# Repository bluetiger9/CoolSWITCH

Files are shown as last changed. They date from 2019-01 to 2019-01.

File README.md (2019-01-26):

# CoolSWITCH

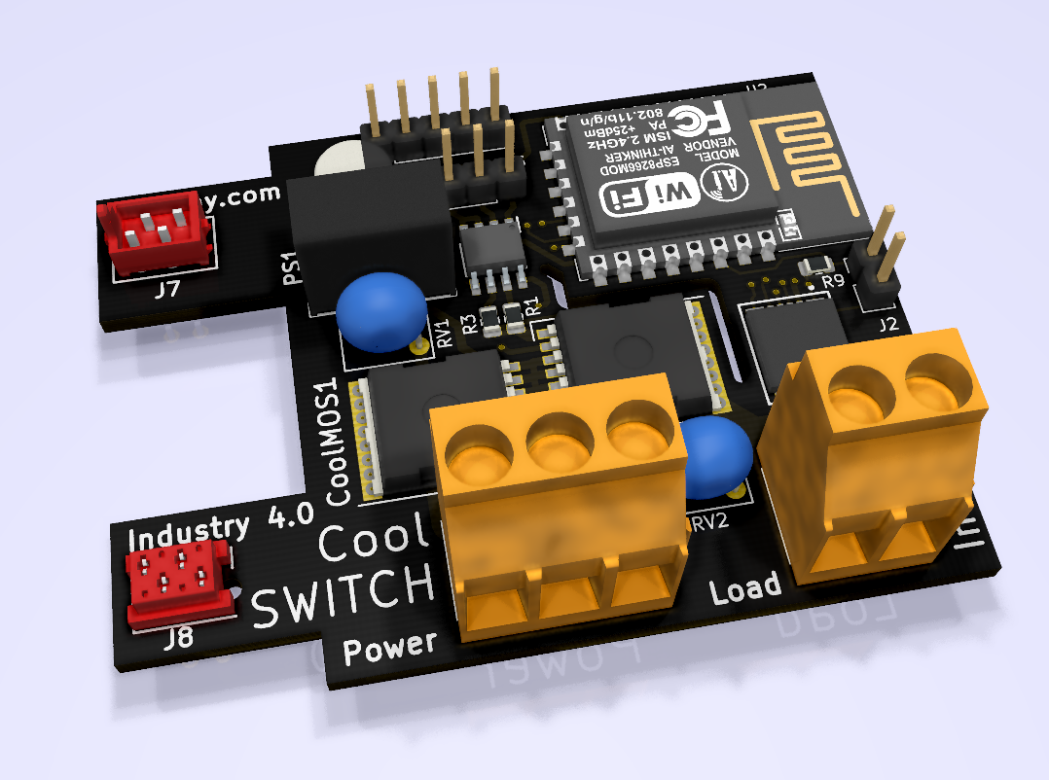
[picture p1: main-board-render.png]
CoolSWITCH


**Project structure**
- CoolSWITH-Kicad - Kicad project: schematics + PCB
- CoolSwitch - Arduino project
- Smashing-Dashboard - Smashing demo dashboard
- MQTT-Grafana - Grafana demo dashboard
- coolSwitchClient.py - secure HTTP client
 
**License**: 
- code: MIT
- kicad design: CC BY-NC-SA

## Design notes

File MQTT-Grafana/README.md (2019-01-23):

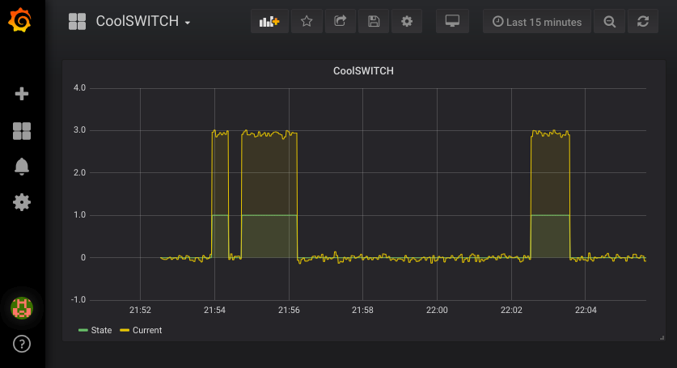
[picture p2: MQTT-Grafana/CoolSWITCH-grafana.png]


**docker-compose.yml**
 - run Mosquitto, InfluxDB and Grafana

**mqttToInflux.py**
 - listens for MQTT message sent by CoolSWITCH-s, and inserts the data into the InfluxDB

**CoolSWITCH-Grafana-Dashboard.json**
 - grafana Dashboard JSON Model

**Based on**:
https://gonzalo123.com/2018/06/04/playing-with-docker-mqtt-grafana-influxdb-python-and-arduino/

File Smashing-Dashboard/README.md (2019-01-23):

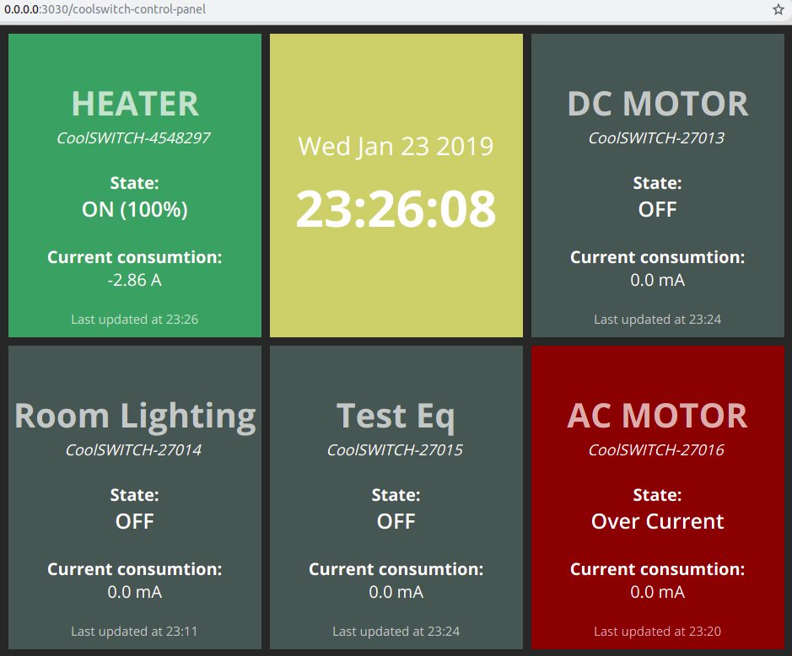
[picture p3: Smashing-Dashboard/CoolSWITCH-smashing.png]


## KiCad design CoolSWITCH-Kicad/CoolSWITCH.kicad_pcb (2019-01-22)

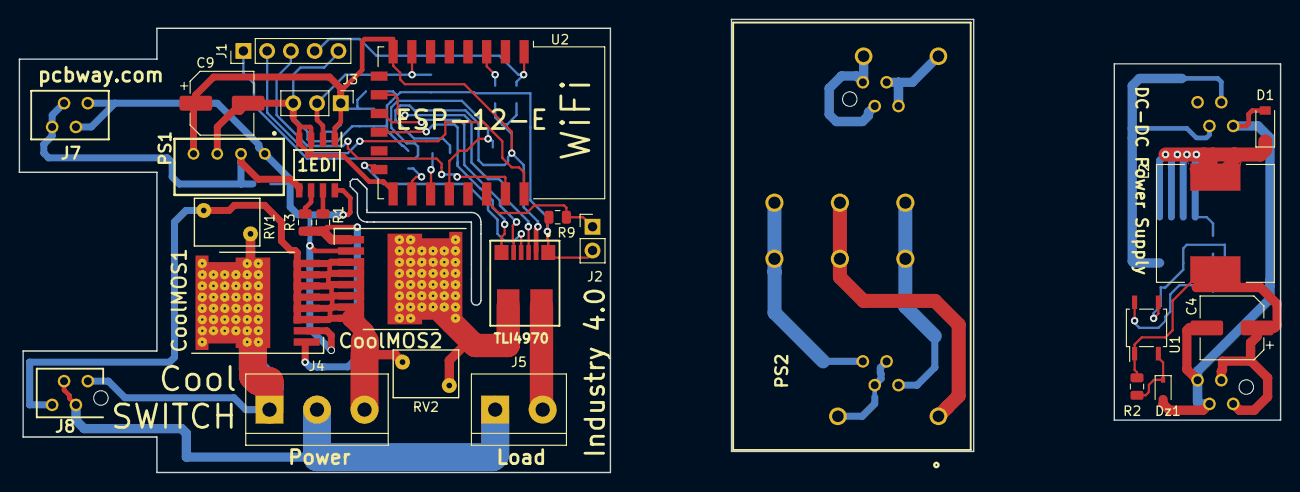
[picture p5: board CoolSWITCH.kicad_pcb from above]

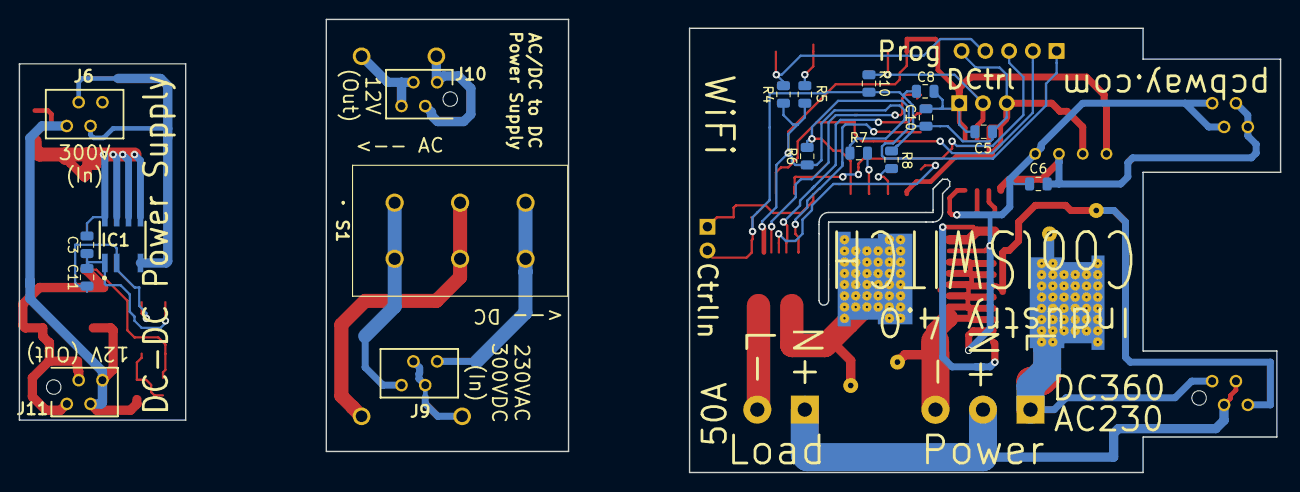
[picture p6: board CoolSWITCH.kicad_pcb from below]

Board: 2 copper layers, 134.9 x 48.5 mm, 44 parts (18 on the bottom side), 38 nets.

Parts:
1EDI: 1EDI20I12MFXUMA1; SOIC127P600X175-8N
C3: 0.1uF (25V); C_0805_2012Metric
C4: 220uF (16V); CP_Elec_6.3x7.7
C5, C8, C10: 100n; C_0805_2012Metric
C6: 1uF; C_0805_2012Metric
C9: 100u; CP_Elec_6.3x5.4
C11: 1nF (25V); C_0805_2012Metric
CoolMOS1, CoolMOS2: IPT60R028G7; Infineon_PG-HSOF-8-1_ThermalVias_fixed
D1: CD1408; D_SOD-123
Dz1: 11V; D_SOD-323
IC1: LNK3206D-TL; LNK3206D
J1: Prog; PinHeader_1x05_P2.54mm_Vertical
J2: CTRL_IN; PinHeader_1x02_P2.54mm_Vertical
J3: Direct_Ctrl; PinHeader_1x03_P2.54mm_Vertical
J4: POWER; TerminalBlock_bornier-3_P5.08mm
J5: LOAD; TerminalBlock_bornier-2_P5.08mm
J6, J9: PS_DC_IN; MicroMatch-215464-4
J7: PS_OUT; MicroMatch-215464-4
J8: PS_IN; MicroMatch-7-215079-4_1
J10: PS_DC_OUT; MicroMatch-7-215079-4_1
J11: PS_AC_OUT; MicroMatch-7-215079-4_1
L2: 1.2uH (400mA); L_12x12mm_H8mm
PS1: IE1203S; IE1224S-H
PS2: IRM-05-12; IRM-05-5
R1: 24 ohm (.5W); R_0805_2012Metric
R2: 1k (1%); R_0805_2012Metric
R3: 48 ohm (.5W); R_0805_2012Metric
R4, R5, R6, R7, R8, R9, R10: 10k; R_0805_2012Metric
RV1, RV2: 599V; RV_Disc_D7mm_W5.1mm_P5mm
S1: X22205CAAK
TLI4970: TLI4970D050T4XUMA1; PG-TISON-8-1
U1: PC817; SOP-4_3.8x4.1mm_P2.54mm
U2: ESP-12E; ESP-12E_2

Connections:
3.3V: 1EDI.1, C5.1, C8.1, C9.1, C10.2, J3.1, PS1.4, R4.1, R5.1, R6.1, R7.1, TLI4970.2, U2.8
12V: 1EDI.5, C6.1, C6.2, J7.1, J7.2, J7.3, J7.4, PS1.1, PS1.2
AC_IN_L: CoolMOS1.6, J4.1, J8.4, RV1.1
AC_IN_N: J4.2, J5.1, J8.2, J8.3
CRNT_CS: TLI4970.5, U2.11
CRNT_DOUT: TLI4970.3, U2.10
CRNT_OCD: TLI4970.6, U2.12
CRNT_SCLK: TLI4970.4, U2.14
CTRL_IN: J2.1, R9.1, U2.20
DC_IN_-: CoolMOS1.3, CoolMOS2.3, J4.3, J8.1, RV1.2, RV2.1
ESP_GPIO0: J1.1, R6.2, U2.18
ESP_RST: J1.4, R4.2, U2.1
ESP_RX: J1.3, U2.21
ESP_TX: J1.2, U2.22
GND: 1EDI.8, CoolMOS1.2, CoolMOS2.2
GND(logic): 1EDI.3, 1EDI.4, C5.2, C8.2, C9.2, C10.1, J1.5, J2.2, J3.3, PS1.3, R8.2, R9.2, R10.2, TLI4970.1, U2.15
Load: J5.2, TLI4970.8
Mosfet_En: 1EDI.2, J3.2, R10.1, U2.7
unnamed: C3.1, D1.1, IC1.5, IC1.6, IC1.7, IC1.8, L2.1
unnamed: C4.1, J11.3, J11.4, L2.2, R2.1, U1.1
unnamed: C4.2, D1.2, Dz1.2, J6.1, J11.1, J11.2
unnamed: C3.2, C11.1, IC1.1, U1.4
unnamed: C11.2, IC1.2, U1.3
unnamed: Dz1.1, R2.2, U1.2
unnamed: IC1.4, J6.2, J6.3
unnamed: 1EDI.6, R3.2
unnamed: 1EDI.7, R1.2
unnamed: CoolMOS2.6, RV2.2, TLI4970.7
unnamed: J9.1, S1.5, S1.6
unnamed: J9.2, J9.3, PS2.4
unnamed: J9.4, S1.1, S1.2
unnamed: J10.1, J10.2, PS2.2
unnamed: J10.3, J10.4, PS2.3
unnamed: PS2.1, S1.3, S1.4
unnamed: CoolMOS1.1, CoolMOS2.1, R1.1, R3.1
unnamed: R5.2, U2.3
unnamed: R7.2, U2.17
unnamed: R8.1, U2.16

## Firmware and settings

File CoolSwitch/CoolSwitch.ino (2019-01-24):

#include <ESP8266WiFi.h>
#include <ESP8266mDNS.h>
#include <WiFiUdp.h>
#include <ArduinoOTA.h>
#include <ESP8266WebServer.h>
#include <Tli4970.h>
#include <Arduino.h>
#include <FS.h>
//#include <SPIFFS.h>

#include "CoolSwitch.hpp"
#include "CoolSwitchHTTP.hpp"
#include "CoolSwitchMQTT.hpp"
#include "CoolSwitchConfig.hpp"

const uint8_t LED = 2;
const uint8_t MOSFET_EN = 13;

CoolSwitchConfig config;
CoolSwitch coolSwitch(MOSFET_EN);
CoolSwitchHTTP httpInterface(coolSwitch, config);
CoolSwitchMQTT mqttInterface(coolSwitch, config);

char deviceId[25];

void setupDeviceId() {
  uint32_t chipid = ESP.getChipId();
  snprintf(deviceId, 25, "CoolSWITCH-%d", chipid);
}

void setupConfig() {
  config.load();
}

void setupWifi() {
  if (config.wifiSSID != "") {
    Serial.print("Connecting to Wifi network: ");
    Serial.println(config.wifiSSID);
    char wifiSSID[32], wifiPassword[32];    
    config.wifiSSID.toCharArray(wifiSSID, 32);
    config.wifiPassword.toCharArray(wifiPassword, 32);
    WiFi.mode(WIFI_STA);
    WiFi.begin(wifiSSID, wifiPassword);
    while (WiFi.waitForConnectResult() != WL_CONNECTED) {
      //config.wifiSSID = "";
      //config.save();
      Serial.println("Connection Failed! Rebooting...");
      delay(5000);
      ESP.restart();
    }
    Serial.println("Wifi connected.");  
    Serial.print("  IP address: ");
    Serial.println(WiFi.localIP());
    
  } else {
    Serial.println("Setting up Wifi Soft AP:");
    WiFi.softAP(deviceId);
    Serial.print("  ssid: ");
    Serial.println(deviceId);
    Serial.print("  ip: 192.168.4.1");
  }  
}

void setupOTA() {
  // Port defaults to 8266
  // ArduinoOTA.setPort(8266);

  // Hostname defaults to esp8266-[ChipID]
  ArduinoOTA.setHostname(deviceId);

  // set OTA password
  if (config.httpSecret != "") {
    char otaPassword[128];
    config.httpSecret.toCharArray(otaPassword, 32);
    ArduinoOTA.setPassword(otaPassword);
  }

  ArduinoOTA.onStart([]() {
    coolSwitch.turnOff();
    Serial.println("Start");
  });
  
  ArduinoOTA.onEnd([]() {
    Serial.println("\nEnd");
  });
  
  ArduinoOTA.onProgress([](unsigned int progress, unsigned int total) {
    Serial.printf("Progress: %u%%\r", (progress / (total / 100)));
  });
  
  ArduinoOTA.onError([](ota_error_t error) {  
    Serial.printf("Error[%u]: ", error);
    if (error == OTA_AUTH_ERROR) Serial.println("Auth Failed");
    else if (error == OTA_BEGIN_ERROR) Serial.println("Begin Failed");
    else if (error == OTA_CONNECT_ERROR) Serial.println("Connect Failed");
    else if (error == OTA_RECEIVE_ERROR) Serial.println("Receive Failed");
    else if (error == OTA_END_ERROR) Serial.println("End Failed");
    ESP.restart();
  });
  
  ArduinoOTA.begin();
}

void setup() {
  Serial.begin(115200);
  Serial.println("Booting");
  pinMode(LED, OUTPUT);  

  setupDeviceId();
  setupConfig();
  setupWifi();
  setupOTA();

  coolSwitch.deviceName = deviceId;

  httpInterface.begin();
  mqttInterface.begin();

  delay(2000);

  coolSwitch.begin();
  
  Serial.println("CoolSWITCH Started.");
}


void loop() {
  ArduinoOTA.handle();
  httpInterface.handle();
  mqttInterface.handle();
  coolSwitch.handle();
  
}

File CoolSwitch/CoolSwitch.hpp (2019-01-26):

#ifndef COOL_SWITCH_H
#define COOL_SWITCH_H

#include "CoolSwitchCurrentSensor.hpp"

enum State { OFF, ON, SOFT_START, SOFT_STOP, OVER_CURRENT } ;

class PWMPin {
public:
  PWMPin(const uint8_t pin) 
    : pin(pin), speed(1024) {    
    pinMode(pin, OUTPUT);
    turnOff();
  };

  void setSpeed(const float speedPercent) {
    uint16_t newSpeed = speedPercent * 1024;
    if (newSpeed == this->speed) {
      return;
    }
    Serial.print("pwm speed: ");
    Serial.println(newSpeed);
    this->speed = newSpeed;
    if (this->on) {
      writeSpeed(this->speed);
    }
  };

  void turnOn() {
    this->on = true; 
    writeSpeed(this->speed);
  };

  void turnOff() {
    this->on = false;
    writeSpeed(0);
  };

private:
  const uint8_t pin;
  uint16_t speed;
  bool on;

  void writeSpeed(uint16_t speed) {
    Serial.print("writeSpeed: ");
    Serial.println(speed);
    analogWrite(pin, speed);
  }; 
};

class CoolSwitch {
public:
  CoolSwitch(const uint8_t pin)
    : state(OFF), pwmPin(pin) {
      
      turnOff();
  }

  void setSpeed(float speed) {
    Serial.print("Speed: ");
    Serial.println(speed);
    this->speed = speed;
    this->pwmPin.setSpeed(speed);
  }

  void setCurrentLimit(float currentLimit) {
    Serial.print("Current limit: ");
    Serial.println(currentLimit);
    this->currentLimit = currentLimit;
  }

  void setSoftSwitchingDuration(uint32_t softSwitchingDuration) {
    Serial.print("Soft switching duration: ");
    Serial.println(softSwitchingDuration);
    this->softSwitchingDuration = softSwitchingDuration;
  }

  void enableSoftStartStop(bool enable) {
    Serial.println(enable ? "Soft switching enabled" : "Soft switching disabled");
    this->softSwitchingEnabled = enable;
  }

  void begin() {
    this->currentSensor.begin();
  }

  void handle() {
    this->currentSensor.handle();

    if (abs(this->currentSensor.getCurrentValue()) > currentLimit) {
      setState(State::OVER_CURRENT);
      return;
    }

    if (state == ON && (millis() - lastHB) > hbOffTimout) {
      setState(State::OFF);
      return;
    }

    if (state == SOFT_START) {
      if (millis() > softSwitchingStarted + softSwitchingDuration) {
        setState(ON);
        
      } else {        
        pwmPin.setSpeed(speed * (((float) millis() - softSwitchingStarted) / softSwitchingDuration));
      }
      
    } else if (state == SOFT_STOP) {
      if (millis() > softSwitchingStarted + softSwitchingDuration) {
        setState(OFF);
        
      } else {        
        pwmPin.setSpeed(speed * (1.0 - ((float) millis() - softSwitchingStarted) / softSwitchingDuration));
      }
    }
  }
  
  void turnOn() { 
    this->lastHB = millis();
    if (this->state == OFF) {
      if (this->softSwitchingEnabled) {
        setState(SOFT_START);
        
      } else {
        setState(ON);
      }
    }    
  }
  
  void turnOff() {
    if (this->state != OFF) {
      if (this->softSwitchingEnabled) {
        setState(SOFT_STOP);
        
      } else {
        setState(OFF);
      }
    }
  }

  void setState(State state) {
    Serial.print("Set state: ");
    Serial.println(state);
    this->state = state;
    switch (state) {
    case ON:
      pwmPin.setSpeed(speed);
      pwmPin.turnOn();
      break;

    case SOFT_START:
      softSwitchingStarted = millis();
      pwmPin.setSpeed(0);
      pwmPin.turnOn();
      break;

    case SOFT_STOP:
      softSwitchingStarted = millis();
      break;
    
    case OFF:
    case OVER_CURRENT:
      pwmPin.turnOff();
      break;
    
    }
  }
  State getState() {
    return this->state;
  }

  State state;
  PWMPin pwmPin;
  CoolSwitchCurrentSensor currentSensor;

  String deviceName;
  
private:
  float currentLimit = 75.0;
  float speed = 1.0;

  bool softSwitchingEnabled = false;
  uint64_t softSwitchingStarted;
  uint32_t softSwitchingDuration = 5000; /* 5 sec */

  uint64_t lastHB = -1;
  uint32_t hbOffTimout = 60000; /* 60 sec */
};

#endif

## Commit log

2019-01-22 CoolSWITCH - add project files
    [CoolSWITCH.kicad_pcb, CoolSWITCH.sch, main-board.kicad_pcb]
2019-01-23 CoolSWITCH - implement soft switching, MQTT, Grafana dashboard, Smashing dashboard
2019-01-26 CoolSWITCH - fix soft start / stop
    [CoolSwitch.hpp]
2019-04-06 fix typo
    [CoolSWITCH.kicad_pcb, CoolSWITCH.sch, main-board.kicad_pcb]
